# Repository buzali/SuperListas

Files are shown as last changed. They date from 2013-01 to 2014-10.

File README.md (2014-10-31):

SuperListas
=============

SuperListas is a consumer electronics device that automates the creation of shopping lists using a barcode scanner. It is simple, when you run out of a product, you scan it and the device automatically creates a shopping list that you can manage online from your computer or smartphone.

### Working Device

Populated front
Populated back
Front PCB

## Introduction

Making grocery lists has been an arduous task, especially for people who plan their grocery shopping mentally, and then create a handwritten list.  This is generally exhausting, particularly to housewives, househusbands and people with full-time jobs.
The constant growth and development of e-commerce and mobile applications has improved the shopping methods of those who have taken advantage of these technologies. Supermarkets have exploited these resources by offering their customers the possibility to order products via web pages or mobile apps. Buyers will receive their products shortly after in the convenience of their doorstep, saving time and effort. 
To take advantage of this new tendency and to solve the main need, a product was developed. This integrated system consists of two parts: an electronic device capable of barcode scanning and WiFi connection, as well as a web platform designed to display a list consisting of the previously scanned products and the possibility of ordering through it. 

## System Architecture

The system comprises of three main modules: the device that scans and transmits the UPC codes, the backend system that processes and stores the data and the frontend interface that lets the user manage and view their grocery lists.

### Embedded Device

The powerful, yet energy efficient microcontroller, Microchip PIC24FJ256GA106 was utilized as the main controller of the embedded device. The microcontroller is connected to the barcode scanner LV1000 that reads the UPC and EAN codes and transmits them via RS232 protocol to the microcontroller. To interface the system with the server, the microcontroller connects via Wi-Fi (IEEE 802.11b) utilizing Microchip’s module, MRF24WB0MA. An LCD display and a rotary encoder are used to interface with the user and display information. In order to store device settings and preferences, an EEPROM memory is also included. To further expand the capabilities of this device, external I/O and USB interfaces were integrated.

Diagram of embeded device

### Backend

Data is exchanged through the use of a RESTful web service built using the Django web framework; written in Python. The API is built to unify the communication between the  backend system and the embedded device and frontend interface.
The embedded device sends a POST request to the web server containing the user ID and a product UPC code. A record is generated in the database. Then a response is built, generally, it contains the product name, price, and category. The information contained in the response is then displayed on the device LCD display as visual feedback for the user.
When the web service tries to match the UPC code against the records in the database, and a record is not found, a request is sent to third party services, which is used to retrieve and cache relevant information about a product.
Accessing the database is done via an Object-relational mapping (ORM) to ease the workflow and use a higher layer of abstraction of the database models.

Backend diagram

### Frontend

Users can access and manage the information recollected by the embedded device by using a web application.
The web application communicates to the backend through the RESTful API, where a user can easily outperform the actions the device is able to do. The user can perform actions such as add or remove a product, modify the quantities, or order the products directly from the supermarket. 
The web application is accessible from mobile devices or computers, allowing the user to access the service while in a supermarket, even several users can manage the grocery list in real time making it possible to add products on the go.

Web Application

## Future Work

There are a plethora of possible future improvements for the platform. Once hundreds of users are using the solution, it will be possible to take advantage of the information collected; statistics about what products are bought, their geographic areas, frequency of purchase, among other. Information that provides. With this data the platform will be able to recommend products to users, based on their previous purchases.
RFID will eventually replace barcodes for grocery tagging, therefore creating new ways of interaction. Products no longer will have to be manually scanned, but they could just be disposed and be automatically scanned, rendering the process effortless.

## Credit

* Tofi Buzali
* David Gomez Urquiza
* Adolfo Bucay

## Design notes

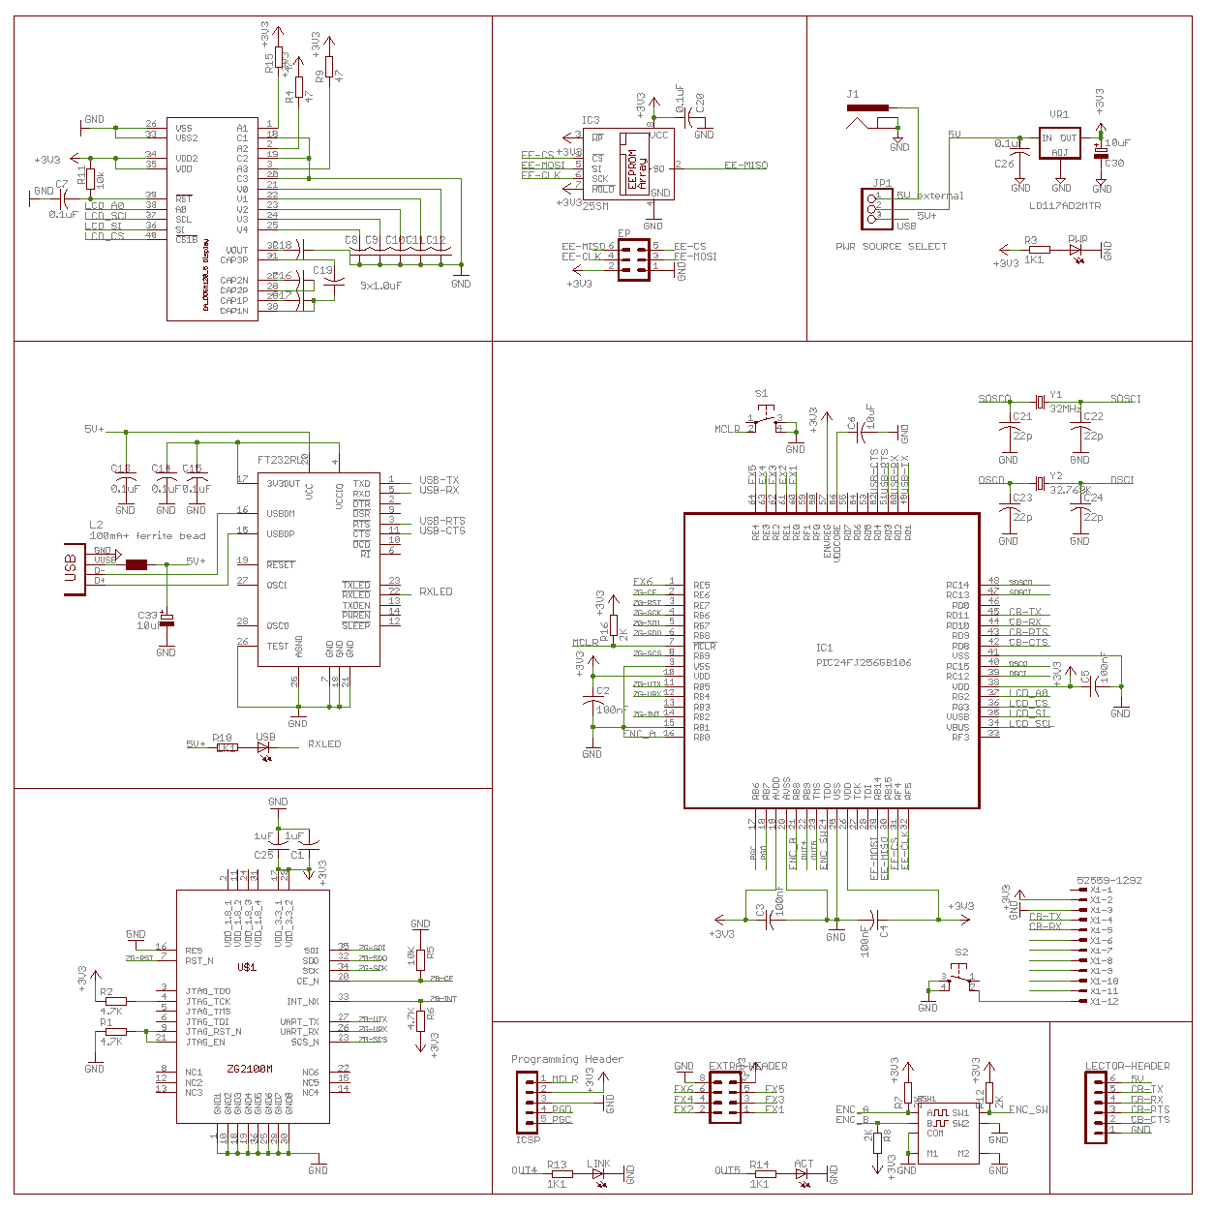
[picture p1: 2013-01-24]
Board/Schematic.png

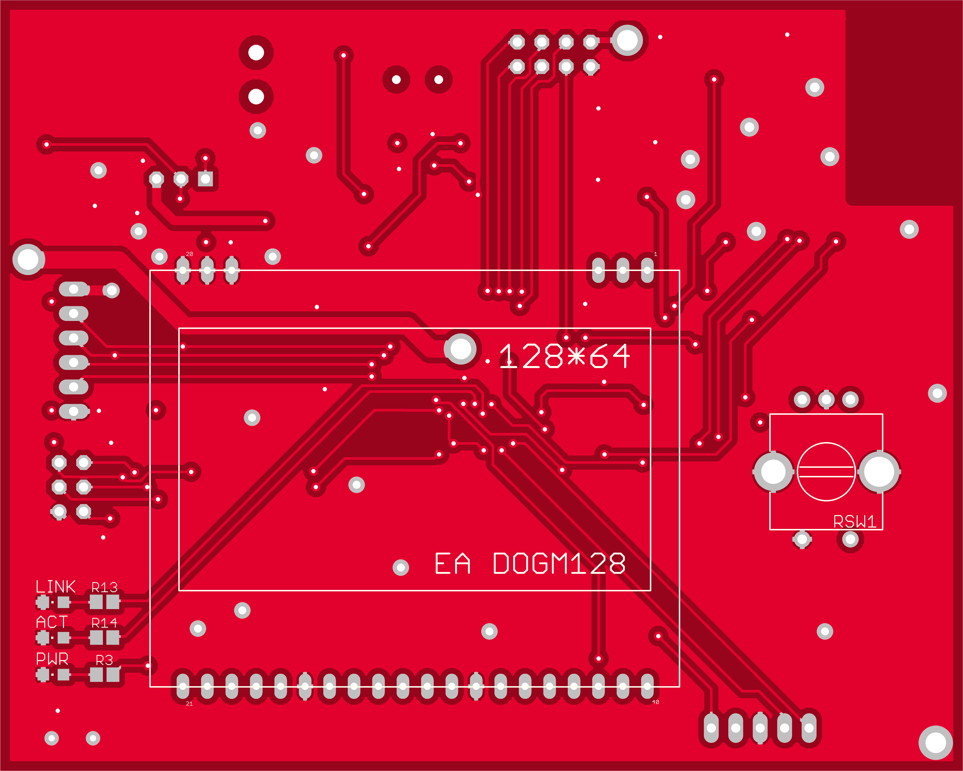
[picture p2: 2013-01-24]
Board/eagle_menu-superlistas-tofi_board_bottom.png

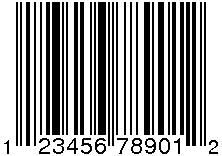
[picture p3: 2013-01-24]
Web Application/superlistas/upc/upcatest.bmp

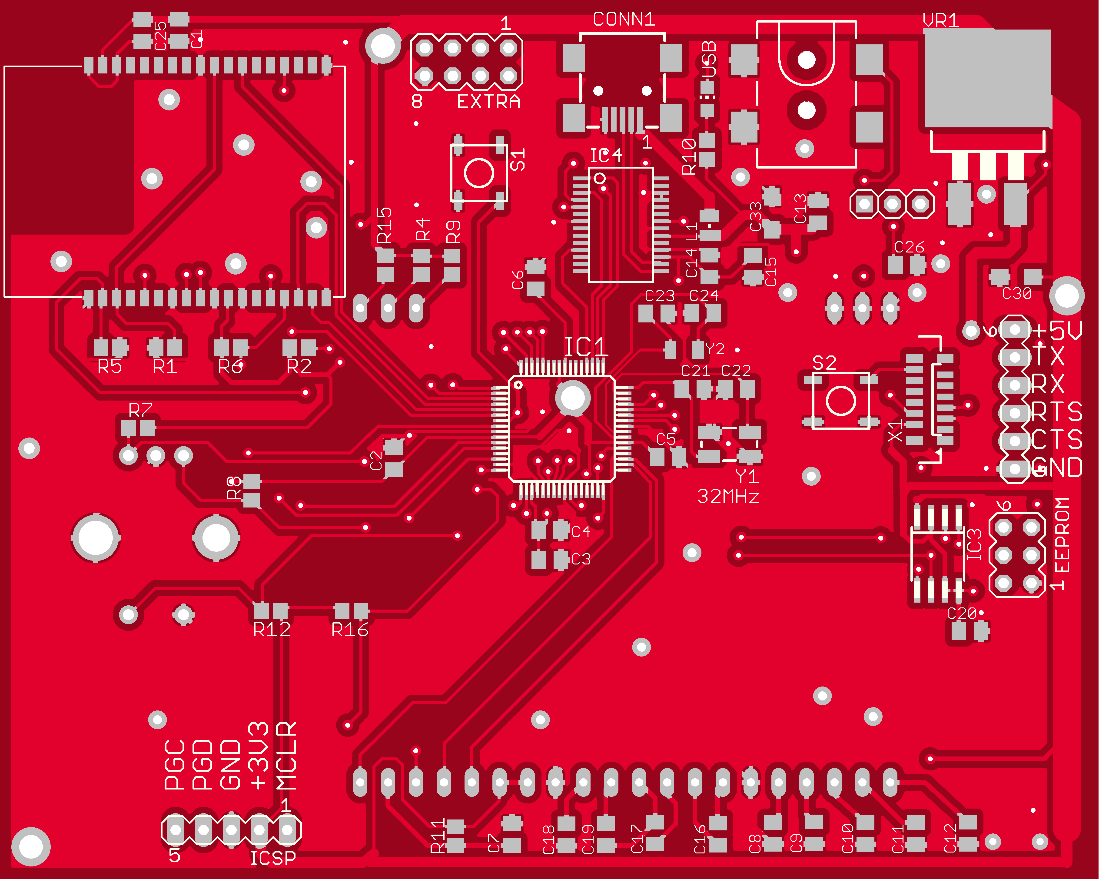
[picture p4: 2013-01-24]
Board/eagle_menu-superlistas-tofi_board_top.png

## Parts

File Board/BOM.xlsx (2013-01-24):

Cantidad | Value | Device | Parts | Mouser | Precio uni Mouser | Precio 100 Mouser | 1000 Mouser | Mejor uni | Precio Mouser (100) | Mejor Precio | Precio USA
1 |  | 52745-1290 | X1 | 538-52745-1297 (https://mx.mouser.com/Search/ProductDetail.aspx) | $1.90 | 1.47 | 1.1 | 1.1 | 1.47 | 1.1
1 |  | EA_DOG-M_DISPLAY | LCD | 790-EADOGM128S6 (https://mx.mouser.com/Search/ProductDetail.aspx) | $23.40 | 16.64 |  | 16.64 | 16.64 | 16.64
4 |  | LEDCHIPLED_0805 | DATA, PWR, USB, WIFI | 696-SML-T0805AWTR (https://mx.mouser.com/Search/ProductDetail.aspx) | $0.234 | 0.195 | 0.137 | 0.137 | 0.78 | 0.548
1 |  | MA03-2 | EEPROM | 579-PIC24256GA106IPT (https://mx.mouser.com/Search/ProductDetail.aspx) | $8.53 | 5.9 |  | 0 | 5.9 | 0
1 |  | MA04-2 | EXTRA |  |  |  |  | 0 | 0 | 0
1 |  | MA05-1 | ICSP |  |  |  |  | 0 | 0 | 0
1 |  | MA06-1 | LECTOR-HEADER |  |  |  |  | 0 | 0 | 0
1 |  | PINHD-1X03_2.54-S | JP1 |  |  |  |  | 0 | 0 | 0
2 |  | SMD_TACT_SMALL | S1, S2 | 688-SKQGAD (https://mx.mouser.com/Search/ProductDetail.aspx?R=SKQGADE010virtualkey68800000virtualkey688-SKQGAD) | $0.923 | 0.65 | 0.325 | 0.325 | 1.3 | 0.65
1 |  | SW-EC11E | RSW1 | 688-EC11K1524402 (https://mx.mouser.com/Search/ProductDetail.aspx) | $3.50 | 2.82 | 2.54 | 2.54 | 2.82 | 2.54
13 | 0.1uF | C-USC0805K | C2, C3, C4, C5, C7, C13, C14, C15, C20, C26, C27, C28, C29 | 80-C0805C104M5R (https://mx.mouser.com/Search/ProductDetail.aspx) | $0.091 | 0.039 | 0.014 | 0.014 | 0.507 | 0.182
4 | 1K1 | R-EU_R0805 | R3, R10, R13, R14 | 71-CRCW0805-1.1K-E3 (https://mx.mouser.com/Search/ProductDetail.aspx) | $0.104 | 0.035 | 0.023 | 0.023 | 0.14 | 0.092
11 | 1uF | C-USC0805K | C1, C8, C9, C10, C11, C12, C16, C17, C18, C19, C25 | 81-GRM21F51H105ZA12L (https://mx.mouser.com/Search/ProductDetail.aspx) | $0.221 | 0.096 | 0.035 | 0.035 | 1.056 | 0.385
4 | 2K | R-EU_R0805 | R7, R8, R12, R16 | 292-2.0K-RC (https://mx.mouser.com/Search/ProductDetail.aspx?R=292-2.0K-RCvirtualkey21980000virtualkey292-2.0K-RC) | $0.052 | 0.026 | 0.022 | 0.022 | 0.104 | 0.088
3 | 4.7K | R-EU_R0805 | R1, R2, R6 | 260-4.7K-RC (https://mx.mouser.com/Search/ProductDetail.aspx?R=260-4.7K-RCvirtualkey21980000virtualkey260-4.7K-RC) | $0.052 | 0.026 | 0.023 | 0.023 | 0.078 | 0.069
2 | 9pF | C-USC0805K | C23, C24 | 140-CC501N9.0D-RC (https://mx.mouser.com/Search/ProductDetail.aspx) | $0.104 | 0.052 | 0.02 | 0.02 | 0.104 | 0.04
2 | 10K | R-EU_R0805 | R5, R11 | 292-10K-RC (https://mx.mouser.com/Search/ProductDetail.aspx?R=292-10K-RCvirtualkey21980000virtualkey292-10K-RC) | $0.052 | 0.026 | 0.022 | 0.022 | 0.052 | 0.044
1 | 10uF | C-USC0805K | C6 | 81-GRM21BR61E106KA3L (https://mx.mouser.com/Search/ProductDetail.aspx) | $0.702 | 0.334 | 0.166 | 0.166 | 0.334 | 0.166
2 | 10uF | CPOL-EUSMCA | C30, C33 | 74-293D106X96R3A2TE3 (https://mx.mouser.com/Search/ProductDetail.aspx) | $0.871 | 0.36 | 0.222 | 0.222 | 0.72 | 0.444
2 | 18pF | C-USC0805K | C21, C22 | 140-CC501N180J-RC (https://mx.mouser.com/Search/ProductDetail.aspx) | $0.078 | 0.044 | 0.017 | 0.017 | 0.088 | 0.034
1 | 25SM | 25SM | IC3 | 579-25LC1024-I/SM (http://mx.mouser.com/ProductDetail/Microchip-Technology/25LC1024-I-SM/) | $4.89 | 3.77 |  | 3.77 | 3.77 | 3.77
1 | 32.768K | FSRLF | Y2 | 559-FSRLF327 (https://mx.mouser.com/Search/ProductDetail.aspx?R=FSRLF327virtualkey55910000virtualkey559-FSRLF327) | $1.08 | 0.096 | 0.624 | 0.624 | 0.096 | 0.624
1 | 32.768K | ST325SB | Y3 | 581-ST3232768E0HPWBB (https://mx.mouser.com/Search/ProductDetail.aspx) | $1.95 | 1.46 | 1.11 | 1.11 | 1.46 | 1.11
1 | 32MHz | TCX_7B_32TXC_7B_32 | Y1 | 717-7B-32.000MEEQ-T (https://mx.mouser.com/Search/ProductDetail.aspx) | $1.82 | 1.04 | 0.728 | 0.728 | 1.04 | 0.728
3 | 47 | R-EU_R0805 | R4, R9, R15 | 260-47-RC (https://mx.mouser.com/Search/ProductDetail.aspx?R=260-47-RCvirtualkey21980000virtualkey260-47-RC) | $0.052 | 0.026 | 0.023 | 0.023 | 0.078 | 0.069
1 | 100mA+ ferrite bead | WE-KIL_0805 | L1 | 81-BLM21BB600SN1D (https://mx.mouser.com/Search/ProductDetail.aspx) | $0.455 | 0.216 | 0.085 | 0.085 | 0.216 | 0.085
1 | CONN_USB | CONN_USB | CONN1 | PRT-00587 (http://www.sparkfun.com/products/587) | $1.50 | 1.2 |  | 1.2 | 1.2 | 1.2
1 | FT232RL | FT232RL | IC4 | COM-00650 (http://www.sparkfun.com/products/650) | $3.95 | 3.16 |  | 3.16 | 3.16 | 3.16
1 | LD117AD2MTR | LD117AD2MTR | VR1 | 512-FAN1587AM33X (https://mx.mouser.com/Search/ProductDetail.aspx) | $4.06 | 2.9 | 1.56 | 1.56 | 2.9 | 1.56
1 | PIC24FJ256GA106 | PIC24FJ256GB106 | IC1 | 579-PIC24256GA106IPT (http://mx.mouser.com/ProductDetail/Microchip-Technology/PIC24FJ256GA106-I-PT/) | $8.53 | 5.9 |  | 4.3 | 5.9 | 4.3
1 | POWER_JACKSMD | POWER_JACKSMD | J1 | 163-0179-EX (https://mx.mouser.com/Search/ProductDetail.aspx?R=163-0179-EXvirtualkey11180000virtualkey163-0179-EX) | $2.03 | 1.42 | 1.18 | 1.18 | 1.42 | 1.18
1 | ZG2100M | ZG2100M | U$1 | 579-MRF24WB0MBRM (https://mx.mouser.com/Search/ProductDetail.aspx) | $38.22 | 29.51 |  | 21.46 | 29.51 | 21.46
1 |  | Backlight |  | 90-EALED55X46E (https://mx.mouser.com/Search/ProductDetail.aspx) | $15.42 | 10.96 |  | 10.96 | 10.96 | 10.96
1 |  | Knob |  | 450-4C618 (https://mx.mouser.com/Search/ProductDetail.aspx?R=450-4C618virtualkey56100000virtualkey450-4C618) | $0.637 | 0.485 | 0.402 | 0.402 | 0.485 | 0.402
1 |  | Cable FFC 3" |  | 538-21020-0121 (https://mx.mouser.com/Search/ProductDetail.aspx) | $4.71 | 3.69 | 2.34 | 2.34 | 3.69 | 2.34
 |  |  |  |  |  |  |  | MEX | 97.978 | 75.97
 |  |  |  |  |  |  |  | USA est | 75.36769231 | 58.43846154

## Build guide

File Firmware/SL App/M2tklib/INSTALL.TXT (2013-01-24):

M2TKLIB
http://code.google.com/p/m2tklib/

Install instructions for the Arduino environment.

1. Install graphics subsystem if required.
      a) "lc": LiquidCrystal: Part of Arduino Environment
      b) "dogm128": dogm128 library, http://code.google.com/p/dogm128/
      c) "glcd": glcd library, http://code.google.com/p/glcd-arduino/
2. Unzip m2tklib_arduino_..._X.XX.zip into the "libraries" folder
3. Start Arduino IDE

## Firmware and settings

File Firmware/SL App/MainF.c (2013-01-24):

/*********************************************************************
 *
 *  Main Application Entry Point based on Microchip TCP/IP DemoAPP 
 */

#define THIS_IS_STACK_APPLICATION

// Include all headers for any enabled TCPIP Stack functions
#include "TCPIP Stack/TCPIP.h"

// Include functions specific to this stack application
#include "MainF.h"
#include <PPS.h>
#include "LCD.h"


// Used for Wi-Fi assertions
#define WF_MODULE_NUMBER   WF_MODULE_MAIN_DEMO

// Declare AppConfig structure and some other supporting stack variables
APP_CONFIG AppConfig;
static unsigned short wOriginalAppConfigChecksum;	// Checksum of the ROM defaults for AppConfig
BYTE AN0String[8];

// Use UART2 instead of UART1 for stdout (printf functions).  Explorer 16 
// serial port hardware is on PIC UART2 module.
#if defined(EXPLORER_16) || defined(PIC24FJ256DA210_DEV_BOARD)
	int __C30_UART = 2;
#endif


// Private helper functions.
// These may or may not be present in all applications.
static void InitAppConfig(void);
static void InitializeBoard(void);
static void ProcessIO(void);
#if defined(WF_CS_TRIS)
    static void WF_Connect(void);
#endif



int main(void)

{
	static DWORD t = 0;
	static DWORD dwLastIP = 0;
	#if defined(WF_USE_POWER_SAVE_FUNCTIONS)
	BOOL  PsPollEnabled;
	BOOL  psConfDone = FALSE;
	#endif

	// Initialize application specific hardware
        
	InitializeBoard();
        

	// Initialize stack-related hardware components that may be 
	// required by the UART configuration routines
        TickInit();
	#if defined(STACK_USE_MPFS2)
	MPFSInit();
	#endif

	// Initialize Stack and application related NV variables into AppConfig.
	InitAppConfig();



    // Initiates board setup process if button is depressed 
	// on startup
    if(BUTTON0_IO == 0)
    {
		#if defined(EEPROM_CS_TRIS) || defined(SPIFLASH_CS_TRIS)
		// Invalidate the EEPROM contents if BUTTON0 is held down for more than 4 seconds
		DWORD StartTime = TickGet();
		LED_PUT(0x00);
				
		while(BUTTON0_IO == 0u)
		{
			if(TickGet() - StartTime > 4*TICK_SECOND)
			{
				#if defined(EEPROM_CS_TRIS)
			    XEEBeginWrite(0x0000);
			    XEEWrite(0xFF);
			    XEEWrite(0xFF);
			    XEEEndWrite();
			    #elif defined(SPIFLASH_CS_TRIS)
			    SPIFlashBeginWrite(0x0000);
			    SPIFlashWrite(0xFF);
			    SPIFlashWrite(0xFF);
			    #endif
			    
				#if defined(STACK_USE_UART)
				putrsUART("\r\n\r\nBUTTON0 held for more than 4 seconds.  Default settings restored.\r\n\r\n");
				#endif

				LED_PUT(0x0F);
				while((LONG)(TickGet() - StartTime) <= (LONG)(9*TICK_SECOND/2));
				LED_PUT(0x00);
				while(BUTTON0_IO == 0u);
				Reset();
				break;
			}
		}
		#endif

		#if defined(STACK_USE_UART)
                DoUARTConfig();
		#endif
    }

	// Initialize core stack layers (MAC, ARP, TCP, UDP) and
	// application modules (HTTP, SNMP, etc.)
    
        LCD_init();
        LCD_printLogo();
    StackInit();

    #if defined(WF_CS_TRIS)
    WF_Connect();
    #endif


    while(1)
    {
	#if defined(WF_USE_POWER_SAVE_FUNCTIONS)
		if (!psConfDone && WFisConnected()) {	
			PsPollEnabled = (MY_DEFAULT_PS_POLL == WF_ENABLED);
			if (!PsPollEnabled) {	 
				/* disable low power (PS-Poll) mode */
				#if defined(STACK_USE_UART)
				putrsUART("Disable PS-Poll\r\n");		 
				#endif
				WF_PsPollDisable();
			} else {
				/* Enable low power (PS-Poll) mode */
				#if defined(STACK_USE_UART)
				putrsUART("Enable PS-Poll\r\n");		
				#endif
				WF_PsPollEnable(TRUE);
			}	
			psConfDone = TRUE;
		}
	#endif
        // Blink LED0 (right most one) every second.
        if(TickGet() - t >= TICK_SECOND/2ul)
        {
            t = TickGet();
            LED0_IO ^= 1;
        }

        // This task performs normal stack task including checking
        // for incoming packet, type of packet and calling
        // appropriate stack entity to process it.
        StackTask();

        // This tasks invokes each of the core stack application tasks
        StackApplications();

 	ProcessIO();

        // If the local IP address has changed (ex: due to DHCP lease change)
        // write the new IP address to the LCD display, UART, and Announce 
        // service
		if(dwLastIP != AppConfig.MyIPAddr.Val)
		{
			dwLastIP = AppConfig.MyIPAddr.Val;
			
			#if defined(STACK_USE_UART)
				putrsUART((ROM char*)"\r\nNew IP Address: ");
			#endif

			DisplayIPValue(AppConfig.MyIPAddr);

			#if defined(STACK_USE_UART)
				putrsUART((ROM char*)"\r\n");
			#endif


			#if defined(STACK_USE_ANNOUNCE)
				AnnounceIP();
			#endif

            #if defined(STACK_USE_ZEROCONF_MDNS_SD)
				mDNSFillHostRecord();
			#endif
		}

        TCPClient();
	}
}

#if defined(WF_CS_TRIS)
/*****************************************************************************
 * FUNCTION: WF_Connect
 *netw
 * RETURNS:  None
 *
 * PARAMS:   None
 *
 *  NOTES:   Connects to an 802.11 network.  Customize this function as needed 
 *           for your application.
 *****************************************************************************/
static void WF_Connect(void)
{
    UINT8 ConnectionProfileID;
    UINT8 channelList[] = MY_DEFAULT_CHANNEL_LIST;
    
    /* create a Connection Profile */
    WF_CPCreate(&ConnectionProfileID);

    #if defined(STACK_USE_UART)
    putrsUART("Set SSID (");
    putsUART(AppConfig.MySSID);
    putrsUART(")\r\n");
    #endif
    WF_CPSetSsid(ConnectionProfileID, 
                 AppConfig.MySSID, 
                 AppConfig.SsidLength);

    #if defined(STACK_USE_UART)
    putrsUART("Set Network Type\r\n");
	#endif
    WF_CPSetNetworkType(ConnectionProfileID, MY_DEFAULT_NETWORK_TYPE);
    
	#if defined(STACK_USE_UART)
	putrsUART("Set Scan Type\r\n");
	#endif
    WF_CASetScanType(MY_DEFAULT_SCAN_TYPE);
    
    #if defined(STACK_USE_UART)
    putrsUART("Set Channel List\r\n");
    #endif    
    WF_CASetChannelList(channelList, sizeof(channelList));
    
    #if defined(STACK_USE_UART)
    putrsUART("Set list retry count\r\n");
    #endif
    // The Retry Count parameter tells the WiFi Connection manager how many attempts to make when trying
    // to connect to an existing network.  In the Infrastructure case, the default is to retry forever so that
    // if the AP is turned off or out of range, the radio will continue to attempt a connection until the
    // AP is eventually back on or in range.  In the Adhoc case, the default is to retry 3 times since the 
    // purpose of attempting to establish a network in the Adhoc case is only to verify that one does not
    // initially exist.  If the retry count was set to WF_RETRY_FOREVER in the AdHoc mode, an AdHoc network
    // would never be established.  The constants MY_DEFAULT_LIST_RETRY_COUNT_ADHOC and 
    // MY_DEFAULT_LIST_RETRY_COUNT_INFRASTRUCTURE have been created specifically for the June 2011 MAL release.
    #if defined(EZ_CONFIG_STORE)
        if (AppConfig.networkType == WF_ADHOC)
            WF_CASetListRetryCount(MY_DEFAULT_LIST_RETRY_COUNT_ADHOC);
        else
            WF_CASetListRetryCount(MY_DEFAULT_LIST_RETRY_COUNT_INFRASTRUCTURE);
    #else
        #if (MY_DEFAULT_NETWORK_TYPE == WF_ADHOC)
            WF_CASetListRetryCount(MY_DEFAULT_LIST_RETRY_COUNT_ADHOC);
        #else
            WF_CASetListRetryCount(MY_DEFAULT_LIST_RETRY_COUNT_INFRASTRUCTURE);
        #endif
    #endif
    

    #if defined(STACK_USE_UART)        
    putrsUART("Set Event Notify\r\n");    
    #endif
    WF_CASetEventNotificationAction(MY_DEFAULT_EVENT_NOTIFICATION_LIST);
    
    #if defined(STACK_USE_UART)
    putrsUART("Set Beacon Timeout\r\n");
    #endif
    WF_CASetBeaconTimeout(40);
    
    /* Set Security */
    #if (MY_DEFAULT_WIFI_SECURITY_MODE == WF_SECURITY_OPEN)
        #if defined(STACK_USE_UART)
        putrsUART("Set Security (Open)\r\n");
        #endif
    #elif (MY_DEFAULT_WIFI_SECURITY_MODE == WF_SECURITY_WEP_40)
        #if defined(STACK_USE_UART)
        putrsUART("Set Security (WEP40)\r\n");
        #endif
    #elif (MY_DEFAULT_WIFI_SECURITY_MODE == WF_SECURITY_WEP_104)
        #if defined(STACK_USE_UART)
        putrsUART("Set Security (WEP104)\r\n");
        #endif
    #elif MY_DEFAULT_WIFI_SECURITY_MODE == WF_SECURITY_WPA_WITH_KEY 
        #if defined(STACK_USE_UART)
        putrsUART("Set Security (WPA with key)\r\n");
        #endif
    #elif MY_DEFAULT_WIFI_SECURITY_MODE == WF_SECURITY_WPA2_WITH_KEY 
        #if defined(STACK_USE_UART)
        putrsUART("Set Security (WPA2 with key)\r\n");
        #endif
    #elif MY_DEFAULT_WIFI_SECURITY_MODE == WF_SECURITY_WPA_WITH_PASS_PHRASE
        #if defined(STACK_USE_UART)
        putrsUART("Set Security (WPA with pass phrase)\r\n");
        #endif
    #elif MY_DEFAULT_WIFI_SECURITY_MODE == WF_SECURITY_WPA2_WITH_PASS_PHRASE
        #if defined(STACK_USE_UART)
        putrsUART("Set Security (WPA2 with pass phrase)\r\n");    
        #endif
    #elif MY_DEFAULT_WIFI_SECURITY_MODE == WF_SECURITY_WPA_AUTO_WITH_KEY
        #if defined(STACK_USE_UART)
        putrsUART("Set Security (WPA with key, auto-select)\r\n");
        #endif
    #elif MY_DEFAULT_WIFI_SECURITY_MODE == WF_SECURITY_WPA_AUTO_WITH_PASS_PHRASE
        #if defined(STACK_USE_UART)
        putrsUART("Set Security (WPA with pass phrase, auto-select)\r\n");
        #endif
    #endif /* MY_DEFAULT_WIFI_SECURITY_MODE */

    WF_CPSetSecurity(ConnectionProfileID,
                     AppConfig.SecurityMode,
                     AppConfig.WepKeyIndex,   /* only used if WEP enabled */
                     AppConfig.SecurityKey,
                     AppConfig.SecurityKeyLength);
    #if defined(STACK_USE_UART)                     
    putrsUART("Start WiFi Connect\r\n");        
    #endif
    WF_CMConnect(ConnectionProfileID);
}   
#endif /* WF_CS_TRIS */

// Writes an IP address to the LCD display and the UART as available
void DisplayIPValue(IP_ADDR IPVal)
{
//	printf("%u.%u.%u.%u", IPVal.v[0], IPVal.v[1], IPVal.v[2], IPVal.v[3]);
#if defined (__dsPIC33E__) || defined (__PIC24E__)
	static BYTE IPDigit[4];    					/* Needs to be declared as static to avoid the array getting optimized by C30 v3.30 compiler for dsPIC33E/PIC24E. 
												   Otherwise the LCD displays corrupted IP address on Explorer 16. To be fixed in the future compiler release*/
#else
    BYTE IPDigit[4];
#endif
	BYTE i;
#ifdef USE_LCD
	BYTE j;
	BYTE LCDPos=16;
#endif

	for(i = 0; i < sizeof(IP_ADDR); i++)
	{
	    uitoa((WORD)IPVal.v[i], IPDigit);

		#if defined(STACK_USE_UART)
			putsUART((char *) IPDigit);
		#endif

		#ifdef USE_LCD
			for(j = 0; j < strlen((char*)IPDigit); j++)
			{
				LCDText[LCDPos++] = IPDigit[j];
			}
			if(i == sizeof(IP_ADDR)-1)
				break;
			LCDText[LCDPos++] = '.';
		#else
			if(i == sizeof(IP_ADDR)-1)
				break;
		#endif

		#if defined(STACK_USE_UART)
			while(BusyUART());
			WriteUART('.');
		#endif
	}

	#ifdef USE_LCD
		if(LCDPos < 32u)
			LCDText[LCDPos] = 0;
		LCDUpdate();
	#endif
}

// Processes A/D data from the potentiometer
static void ProcessIO(void)
{
#if defined(__C30__) || defined(__C32__)
    // Convert potentiometer result into ASCII string
    uitoa((WORD)ADC1BUF0, AN0String);
#else
    // AN0 should already be set up as an analog input
    ADCON0bits.GO = 1;

    // Wait until A/D conversion is done
    while(ADCON0bits.GO);

	// AD converter errata work around (ex: PIC18F87J10 A2)
	#if !defined(__18F87J50) && !defined(_18F87J50) && !defined(__18F87J11) && !defined(_18F87J11) 
	{
		BYTE temp = ADCON2;
		ADCON2 |= 0x7;	// Select Frc mode by setting ADCS0/ADCS1/ADCS2
		ADCON2 = temp;
	}
	#endif

    // Convert 10-bit value into ASCII string
    uitoa(*((WORD*)(&ADRESL)), AN0String);
#endif
}


/****************************************************************************
  Function:
    static void InitializeBoard(void)

  Description:
    This routine initializes the hardware.  It is a generic initialization
    routine for many of the Microchip development boards, using definitions
    in HardwareProfile.h to determine specific initialization.

  Precondition:
    None

  Parameters:
    None - None

  Returns:
    None

  Remarks:
    None
  ***************************************************************************/
static void InitializeBoard(void)
{

    AD1PCFGL = 0xFFFF; 
	// LEDs
	LED0_TRIS = 0;
	LED1_TRIS = 0;
	LED2_TRIS = 0;
	LED3_TRIS = 0;
	LED4_TRIS = 0;
	LED5_TRIS = 0;
	LED6_TRIS = 0;
	LED7_TRIS = 0;
	LED_PUT(0x03);

        
        BUTTON0_TRIS=1;



        CLKDIVbits.RCDIV = 0;		// Set 1:1 8MHz FRC postscalar

		
		// ADC


	// UART
	#if defined(STACK_USE_UART)

		UARTTX_TRIS = 0;
		UARTRX_TRIS = 1;
		UMODE = 0x8000;			// Set UARTEN.  Note: this must be done before setting UTXEN
                USTA = 0x0400;		// UTXEN set
		#define CLOSEST_UBRG_VALUE ((GetPeripheralClock()+8ul*BAUD_RATE)/16/BAUD_RATE-1)
		#define BAUD_ACTUAL (GetPeripheralClock()/16/(CLOSEST_UBRG_VALUE+1))
		#define BAUD_ERROR ((BAUD_ACTUAL > BAUD_RATE) ? BAUD_ACTUAL-BAUD_RATE : BAUD_RATE-BAUD_ACTUAL)
		#define BAUD_ERROR_PRECENT	((BAUD_ERROR*100+BAUD_RATE/2)/BAUD_RATE)
		#if (BAUD_ERROR_PRECENT > 3)
			#warning UART frequency error is worse than 3%
		#elif (BAUD_ERROR_PRECENT > 2)
			#warning UART frequency error is worse than 2%
		#endif
		UBRG = CLOSEST_UBRG_VALUE;
	#endif


        //init_CB_UART

	// This is an EXAMPLE, so brutal typing goes into explaining all bit sets

	// The Explorer 16 board has a DB9 connector wired to UART2, so we will
	// be configuring this port only

	// configure U2MODE
        U1MODE = 0;

        #define CB_BAUD_RATE   9600
        #define CLOSEST_CB_UBRG_VALUE ((GetPeripheralClock()+8ul*CB_BAUD_RATE)/16/CB_BAUD_RATE-1)
        #define CB_BAUD_ACTUAL (GetPeripheralClock()/16/(CLOSEST_CB_UBRG_VALUE+1))
	#define CB_BAUD_ERROR ((CB_BAUD_ACTUAL > BAUD_RATE) ? CB_BAUD_ACTUAL-CB_BAUD_RATE : CB_BAUD_RATE-CB_BAUD_ACTUAL)
	#define CB_BAUD_ERROR_PRECENT	((CB_BAUD_ERROR*100+CB_BAUD_RATE/2)/CB_BAUD_RATE)
	#if (CB_BAUD_ERROR_PRECENT > 3)
		#warning UART frequency error is worse than 3%
	#elif (CB_BAUD_ERROR_PRECENT > 2)
		#warning UART frequency error is worse than 2%
	#endif
	U1BRG = CLOSEST_CB_UBRG_VALUE;

	// Load all values in for U1STA SFR
        U1STA =0;
	IFS0bits.U1TXIF = 0;	// Clear the Transmit Interrupt Flag
	IEC0bits.U1TXIE = 0;	// Enable Transmit Interrupts
	IFS0bits.U1RXIF = 0;	// Clear the Recieve Interrupt Flag
	IEC0bits.U1RXIE = 1;	// Enable Recieve Interrupts

	U1MODEbits.UARTEN = 1;	// And turn the peripheral on
	U1STAbits.UTXEN = 1;




// Deassert all chip select lines so there isn't any problem with 
// initialization order.  Ex: When ENC28J60 is on SPI2 with Explorer 16, 
// MAX3232 ROUT2 pin will drive RF12/U2CTS ENC28J60 CS line asserted, 
// preventing proper 25LC256 EEPROM operation.

#if defined(WF_CS_TRIS)
	WF_CS_IO = 1;
	WF_CS_TRIS = 0;
#endif


#if defined(__PIC24FJ256GA106__)
/*
	__builtin_write_OSCCONL(OSCCON & 0xBF);

	RPOR10bits.RP21R = 8;	// Assign RG6/RP21 to SCK1 (output)
	RPOR13bits.RP26R = 7;	// Assign RG8/RP19 to SDO1 (output)
	RPOR11bits.RP23R = 5;	// Assign RD1/RP24 to U2TX (output)


	RPINR20bits.SDI1R = 19;	// Assign RG7/RP26 to SDI1 (input)
	RPINR0bits.INT1R = 13;	// Assign RB2/RP13 to INT1 (input)
	RPINR19bits.U2RXR = 24;	// Assign RD2/RP23 to U2RX (input)
	__builtin_write_OSCCONL(OSCCON | 0x40); // Lock PPS
*/

    PPSUnLock;

    iPPSOutput(WF_SCK_RP, OUT_FN_PPS_SCK1OUT);
    iPPSOutput(WF_SDO_RP, OUT_FN_PPS_SDO1);
    iPPSOutput(TX_RP, OUT_FN_PPS_U2TX);

    iPPSOutput(CB_TX_RP, OUT_FN_PPS_U1TX);
    iPPSOutput(LCD_SO_RP, OUT_FN_PPS_SDO2);
    iPPSOutput(LCD_SCL_RP, OUT_FN_PPS_SCK2OUT);


    iPPSInput(IN_FN_PPS_U1RX, CB_RX_RPPIN);
    //PPSInput(IN_FN_PPS_INT1, ENC_A_RPPIN);
    //iPPSInput(IN_FN_PPS_INT2, ENC_B_RPPIN);
    iPPSInput(IN_FN_PPS_SDI1, WF_SDI_RPPIN);
    iPPSInput(IN_FN_PPS_INT1, WF_INT_RPPIN);
    iPPSInput(IN_FN_PPS_U2RX, RX_RPPIN);
    PPSLock;
        
#endif

}

/*********************************************************************
 * Function:        void InitAppConfig(void)
 *
 * PreCondition:    MPFSInit() is already called.
 *
 * Input:           None
 *
 * Output:          Write/Read non-volatile config variables.
 *
 * Side Effects:    None
 *
 * Overview:        None
 *
 * Note:            None
 ********************************************************************/
// MAC Address Serialization using a MPLAB PM3 Programmer and 
// Serialized Quick Turn Programming (SQTP). 
// The advantage of using SQTP for programming the MAC Address is it
// allows you to auto-increment the MAC address without recompiling 
// the code for each unit.  To use SQTP, the MAC address must be fixed
// at a specific location in program memory.  Uncomment these two pragmas
// that locate the MAC address at 0x1FFF0.  Syntax below is for MPLAB C 
// Compiler for PIC18 MCUs. Syntax will vary for other compilers.
//#pragma romdata MACROM=0x1FFF0
static ROM BYTE SerializedMACAddress[6] = {MY_DEFAULT_MAC_BYTE1, MY_DEFAULT_MAC_BYTE2, MY_DEFAULT_MAC_BYTE3, MY_DEFAULT_MAC_BYTE4, MY_DEFAULT_MAC_BYTE5, MY_DEFAULT_MAC_BYTE6};
//#pragma romdata
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

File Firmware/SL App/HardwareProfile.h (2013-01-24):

#ifndef HARDWARE_PROFILE_H
#define HARDWARE_PROFILE_H

#include "Compiler.h"
//#include "/Users/Tofi/Desktop/Firmware/HWProfile.h"


// Set configuration fuses (but only in MainF.c where THIS_IS_STACK_APPLICATION is defined)
#if defined(THIS_IS_STACK_APPLICATION)
_CONFIG2(FNOSC_PRI & POSCMOD_HS & IOL1WAY_OFF)// Primary HS OSC
_CONFIG1(JTAGEN_OFF & FWDTEN_OFF & ICS_PGx2)		// JTAG off, watchdog timer off

#endif


// Clock frequency values

#if defined (BETA_1)
#define MAXIMUM_PIC_FREQ		(9830400ul)
#elif defined (BETA_2)
#define MAXIMUM_PIC_FREQ		(32000000ul)
#endif


// These directly influence timed events using the Tick module.  They also are used for UART and SPI baud rate generation.
#define GetSystemClock()		(MAXIMUM_PIC_FREQ)			// Hz
#define GetInstructionClock()	(GetSystemClock()/2)	// Normally GetSystemClock()/4 for PIC18, GetSystemClock()/2 for PIC24/dsPIC, and GetSystemClock()/1 for PIC32.  Might need changing if using Doze modes.
#define GetPeripheralClock()	(GetSystemClock()/2)	// Normally GetSystemClock()/4 for PIC18, GetSystemClock()/2 for PIC24/dsPIC, and GetSystemClock()/1 for PIC32.  Divisor may be different if using a PIC32 since it's configurable.
#define FCY                     GetInstructionClock()

// Peripheral Pin Select pin output registers
#define RP0_O   RPOR0bits.RP0R
#define RP1_O   RPOR0bits.RP1R
#define RP2_O   RPOR1bits.RP2R
#define RP3_O   RPOR1bits.RP3R
#define RP4_O   RPOR2bits.RP4R

#define RP6_O   RPOR3bits.RP6R
#define RP7_O   RPOR3bits.RP7R
#define RP8_O   RPOR4bits.RP8R
#define RP9_O   RPOR4bits.RP9R
#define RP10_O  RPOR5bits.RP10R
#define RP11_O  RPOR5bits.RP11R
#define RP12_O  RPOR6bits.RP12R
#define RP13_O  RPOR6bits.RP13R
#define RP14_O  RPOR7bits.RP14R

#define RP16_O  RPOR8bits.RP16R
#define RP17_O  RPOR8bits.RP17R
#define RP18_O  RPOR9bits.RP18R
#define RP19_O  RPOR9bits.RP19R
#define RP20_O  RPOR10bits.RP20R
#define RP21_O  RPOR10bits.RP21R
#define RP22_O  RPOR11bits.RP22R
#define RP23_O  RPOR11bits.RP23R
#define RP24_O  RPOR12bits.RP24R
#define RP25_O  RPOR12bits.RP25R
#define RP26_O  RPOR13bits.RP26R
#define RP27_O  RPOR13bits.RP27R
#define RP28_O  RPOR14bits.RP28R
#define RP29_O  RPOR14bits.RP29R
#define RP30_O  RPOR15bits.RP30R


//these are shortcut names for the LED and IO pins
#define EX6_TRIS                (TRISEbits.TRISE5)
#define EX6_I                   (PORTEbits.RE5)
#define EX6_O                   (LATEbits.LATE5)
#define EX5_TRIS                (TRISEbits.TRISE4)
#define EX5_I                   (PORTEbits.RE4)
#define EX5_O                   (LATEbits.LATE4)
#define EX4_TRIS                (TRISEbits.TRISE3)
#define EX4_I                   (PORTEbits.RE3)
#define EX4_O                   (LATEbits.LATE3)
#define EX3_TRIS                (TRISEbits.TRISE2)
#define EX3_I                   (PORTEbits.RE2)
#define EX3_O                   (TRISEbits.TRISE2)
#define EX2_TRIS                (LATEbits.LATE1)
#define EX2_I                   (PORTEbits.RE1)
#define EX2_O                   (LATEbits.LATE1)
#define EX1_TRIS                (TRISEbits.TRISE0)
#define EX1_I                   (PORTEbits.RE0)
#define EX1_O                   (LATEbits.LATE0)

#define OUT4_TRIS               (TRISBbits.TRISB9)
#define OUT4_I                  (PORTBbits.RB9)
#define OUT4_O                  (LATBbits.LATB9)
#define OUT5_TRIS               (TRISBbits.TRISB10)
#define OUT5_I                  (PORTBbits.RB10)
#define OUT5_O                  (LATBbits.LATB10)
#define WIFI_LED_TRIS           (TRISBbits.TRISB9)
#define WIFI_LED_I              (PORTBbits.RB9)
#define WIFI_LED_O              (LATBbits.LATB9)
#define DATA_LED_TRIS           (TRISBbits.TRISB10)
#define DATA_LED_I              (PORTBbits.RB10)
#define DATA_LED_O              (LATBbits.LATB10)

#define USB_CTS_TRIS            (TRISDbits.TRISD4)
#define USB_CTS_I               (PORTDbits.RD4)
#define USB_CTS_O               (LATDbits.LATD4)
#define USB_RTS_TRIS            (TRISDbits.TRISD3)
#define USB_RTS_I               (PORTDbits.RD3)
#define USB_RTS_O               (LATDbits.LATD3)
#define USB_TX_TRIS             (TRISDbits.TRISD1)
#define USB_TX_I                (PORTDbits.RD1)
#define USB_TX_O                (LATDbits.LATD1)
#define USB_RX_TRIS             (TRISDbits.TRISD2)
#define USB_RX_I                (PORTDbits.RD2)
#define USB_RX_O                (LATDbits.LATD2)
//Invertido
#define TX_TRIS                 (TRISDbits.TRISD2)
#define TX_I                    (PORTDbits.RD2)
#define TX_O                    (LATDbits.LATD2)
#define TX_RP                   RP23_O
#define RX_TRIS                 (TRISDbits.TRISD1)
#define RX_I                    (PORTDbits.RD1)
#define RX_O                    (LATDbits.LATD1)
#define RX_RPPIN                24
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

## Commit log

2013-01-24 all files
    [BOM.xlsx, menu-superlistas-tofi.brd, menu-superlistas-tofi.sch]
2013-01-24 added schematic in PDF
2013-05-21 Update README.md
    Added pictures of working device
